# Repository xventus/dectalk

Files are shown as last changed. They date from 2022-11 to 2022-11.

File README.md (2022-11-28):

# DECTALK 

DECTALK is a simple application of Epson's S1V30120 chip. The communication is controlled by the ESP32 module. Esp32 provides HTTP and serial access for control. MIKROE produces a suitable module carrying the S1V30120 and an amplifier. 

The hardware directory contains a schematic and a board of plenum connections in KICAD format.
The src directory contains the source code for ESP32.

# How to use it 

The module can communicate using HTTP protocol via WiFi or using a serial link.

WiFi connection:
	- on first run, create an AP named `DECTALK CONFIG` or press reset (EN) twice within 5 seconds. 
	- web browser http://192.168.4.100 and fill in the web form

 	POST via build in fomular:  http://192.168.2.220/talk
 	POST via build in fomular:  http://192.168.2.220
	GET with url encoded string as param:   http://XXX.XXX.XXX.XXX/talk?talk=hello%20world

Serial line connection:
	- 9600.8.N.1 

LED status on the ESP32 module:
 - fast LED blinking - error, more detail after serial line
 - slow blinking LED - runs as AP `DECTALK CONFIG`
 - turns on and then off - when playing a message

# Device limitations

The message length is limited to 248 characters.

# Documentation 

S1V30120 module:  https://www.mikroe.com/text-to-speech-click.

S1V30120 initialization data: https://global.epson.com/products_and_drivers/semicon/products/speech/voice/sla/s1v30120_init_data.html

S1V30120 protocol: https://global.epson.com/products_and_drivers/semicon/pdf/id001875.pdf

# Screens

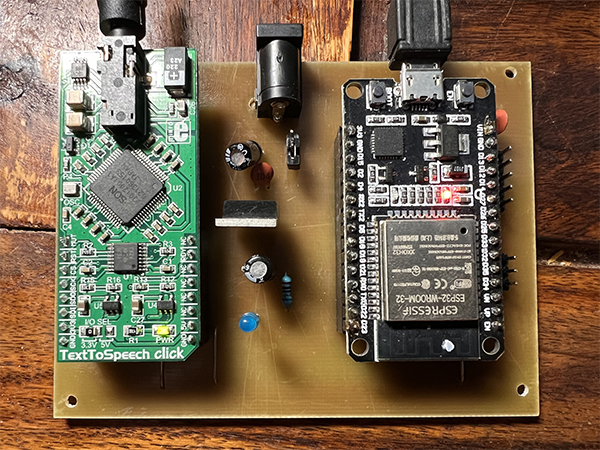
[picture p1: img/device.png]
device

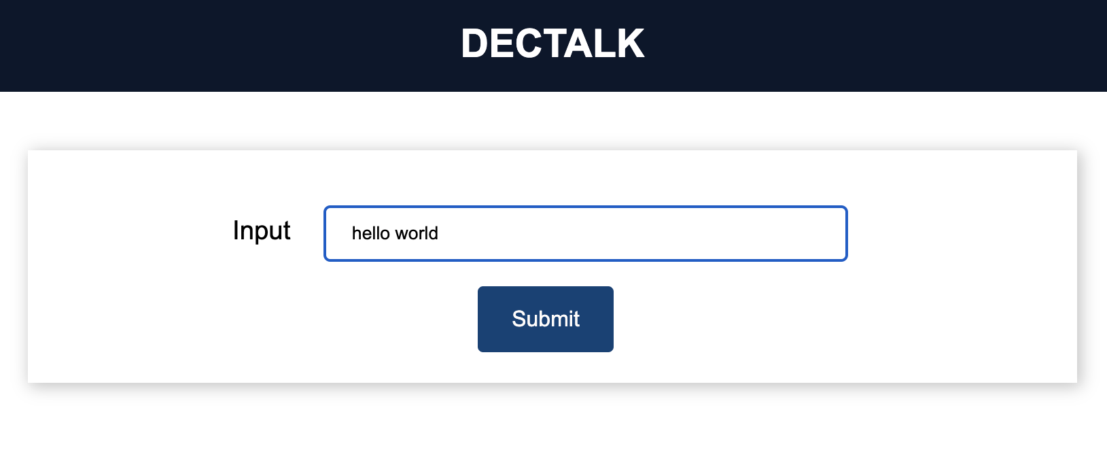
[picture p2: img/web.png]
dectalk screen

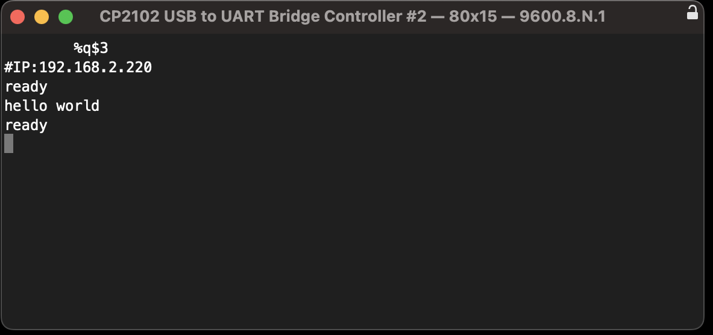
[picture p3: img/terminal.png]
terminal


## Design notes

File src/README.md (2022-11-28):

# Compilation for ESP32 module

1, Visual Studio Code + Platformio

2, in platformio.ini set the correct serial port e.g. upload_port = /dev/cu.usbserial-0001

3, upload to ESP32 filesytem using GUI - Upload Filesystem Image

4, upload own program - Upload

6, on first run, create an AP named `DECTALK CONFIG` or press reset (EN) twice within 5 seconds. 

7, web browser http://192.168.4.100 and fill in the web form

8, restart

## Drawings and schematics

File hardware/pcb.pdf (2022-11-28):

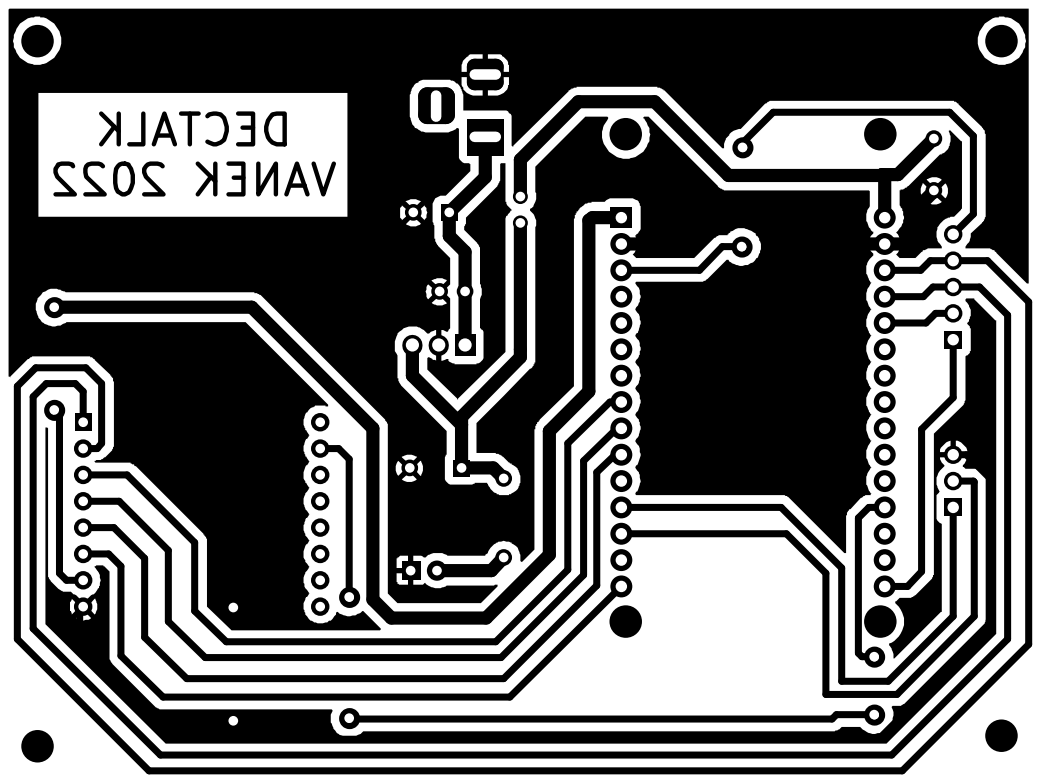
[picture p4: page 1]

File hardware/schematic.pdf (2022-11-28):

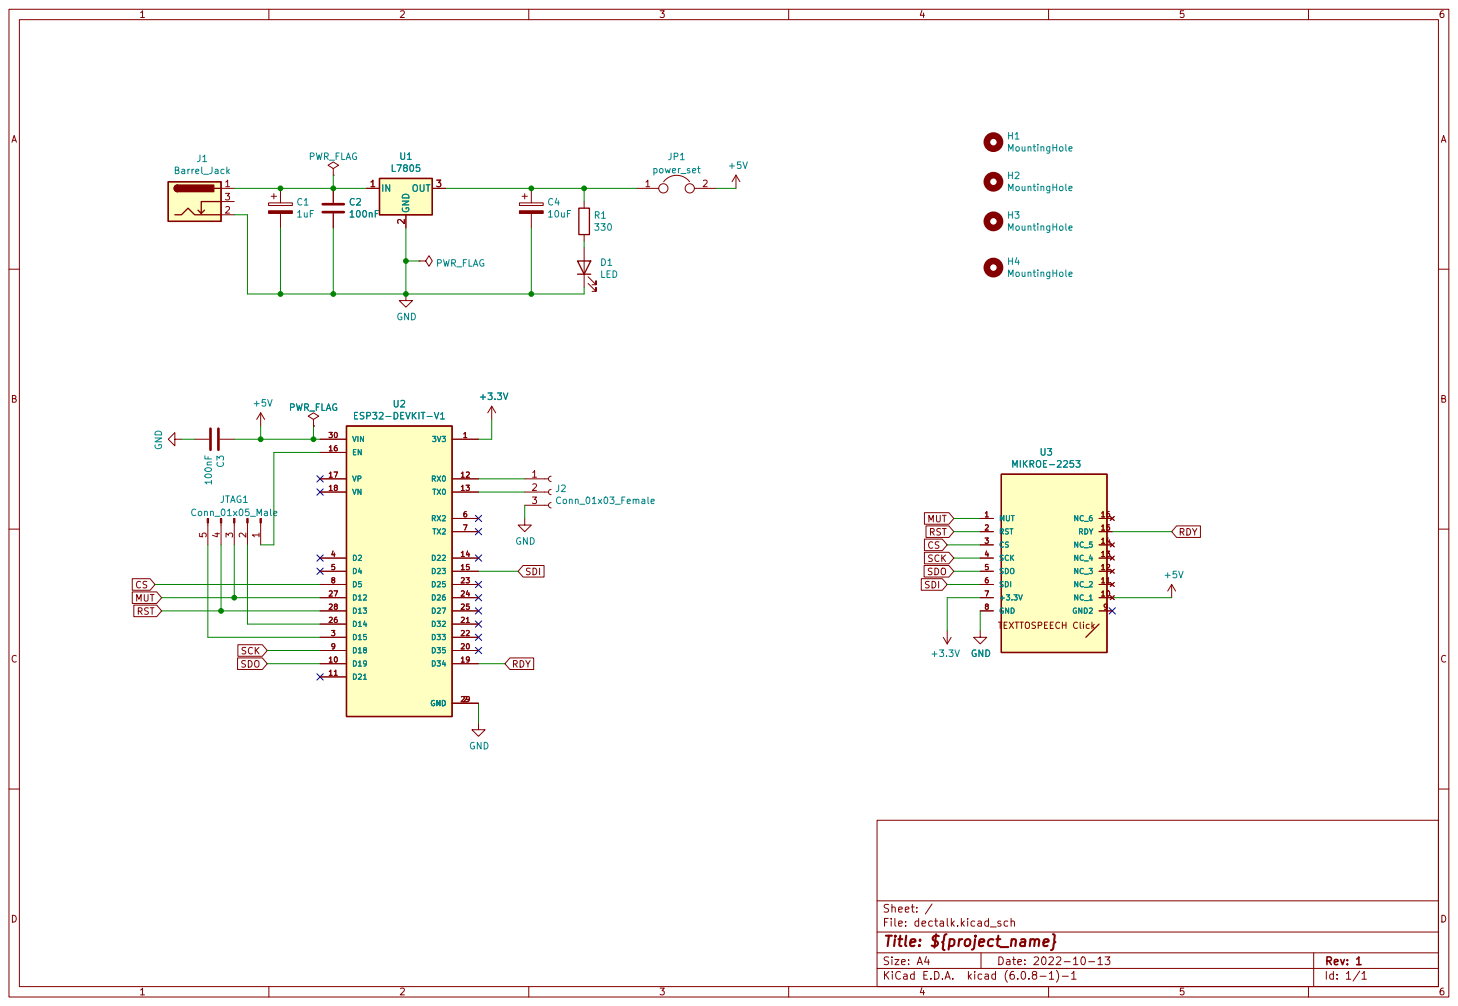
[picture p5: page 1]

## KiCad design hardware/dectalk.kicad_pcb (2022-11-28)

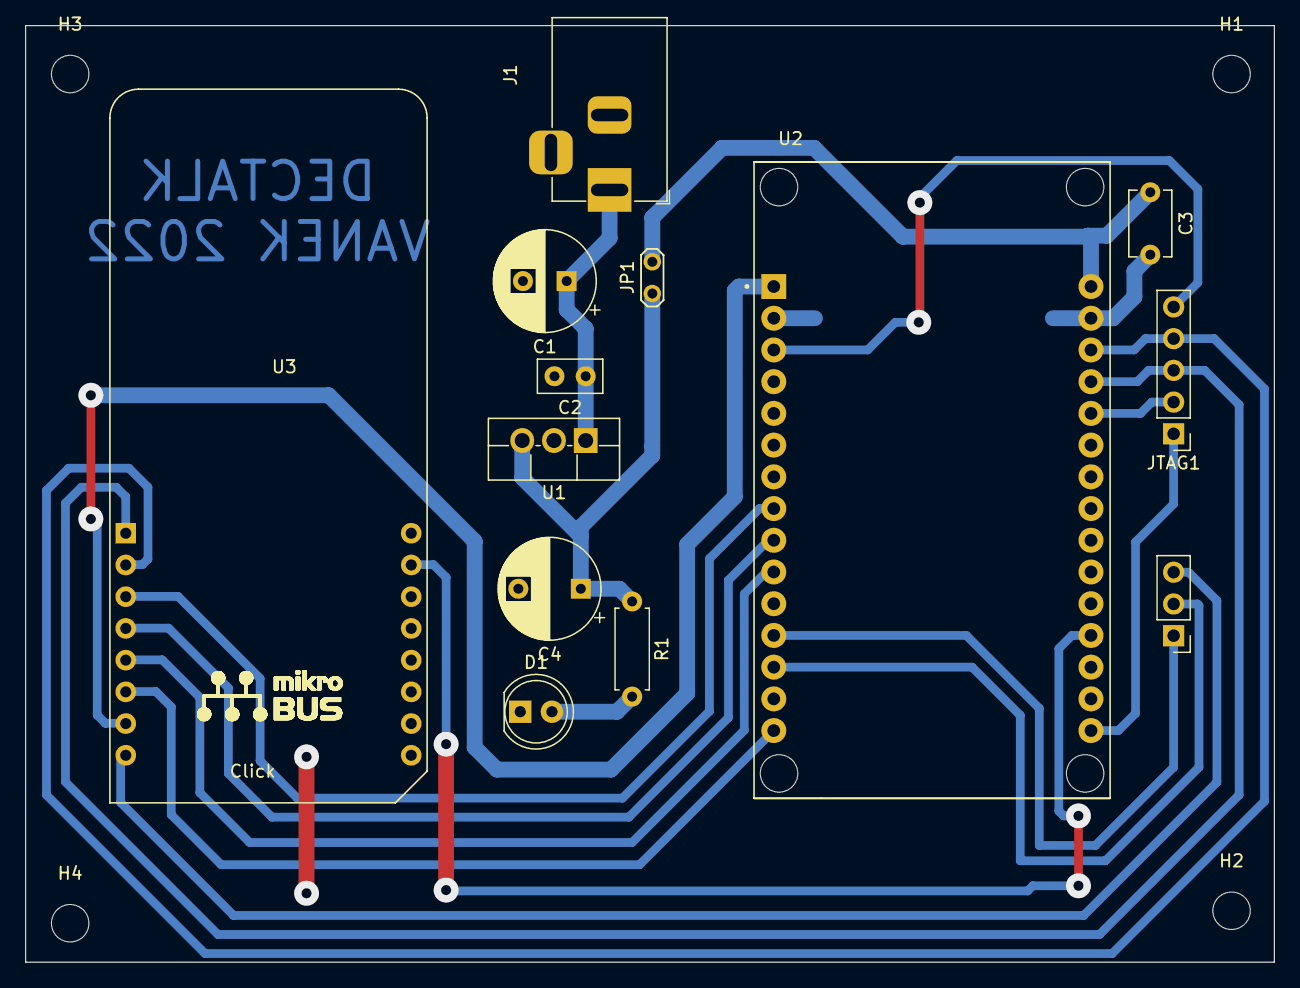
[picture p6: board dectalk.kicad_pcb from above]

Board: 2 copper layers, 100.0 x 75.0 mm, 17 parts (0 on the bottom side), 18 nets.

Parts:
C1: 1uF; CP_Radial_D8.0mm_P3.50mm
C2: 100nF; C_Disc_D5.0mm_W2.5mm_P2.50mm
C3: 100nF; C_Disc_D5.1mm_W3.2mm_P5.00mm
C4: 10uF; CP_Radial_D8.0mm_P5.00mm
D1: LED; LED_D5.0mm_IRGrey
H1, H2, H3, H4: MountingHole; MountingHole_3mm
J1: Barrel_Jack; BarrelJack_Horizontal
J2: Conn_01x03_Female; PinHeader_1x03_P2.54mm_Vertical
JP1: power_set; TestPoint_2Pads_Pitch2.54mm_Drill0.8mm
JTAG1: Conn_01x05_Male; PinHeader_1x05_P2.54mm_Vertical
R1: 330; R_Axial_DIN0207_L6.3mm_D2.5mm_P7.62mm_Horizontal
U1: L7805; TO-220F-3_Vertical
U2: ESP32-DEVKIT-V1; MODULE_ESP32_DEVKIT_V1
U3: MIKROE-2253

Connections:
+3V3: U2.1 (3V3), U3.7 (+3.3V)
+5V: C3.1, JP1.2, U2.30 (VIN)
CS: U2.8 (D5), U3.3 (CS)
GND: C1.2, C2.2, C3.2, C4.2, D1.1 (K), J1.2, J2.3, U1.2 (GND), U2.2 (GND), U2.29 (GND), U3.8 (GND)
MUT: JTAG1.3, U2.27 (D12), U3.1 (MUT)
unnamed: C1.1, C2.1, J1.1, U1.1 (IN)
unnamed: C4.1, JP1.1, R1.1, U1.3 (OUT)
unnamed: D1.2 (A), R1.2
unnamed: J2.1, U2.12 (RX0)
unnamed: J2.2, U2.13 (TX0)
unnamed: JTAG1.5, U2.3 (D15)
unnamed: JTAG1.1, U2.16 (EN)
unnamed: JTAG1.2, U2.26 (D14)
RDY: U2.19 (D34), U3.15 (RDY)
RST: JTAG1.4, U2.28 (D13), U3.2 (RST)
SCK: U2.9 (D18), U3.4 (SCK)
SDI: U2.15 (D23), U3.6 (SDI)
SDO: U2.10 (D19), U3.5 (SDO)

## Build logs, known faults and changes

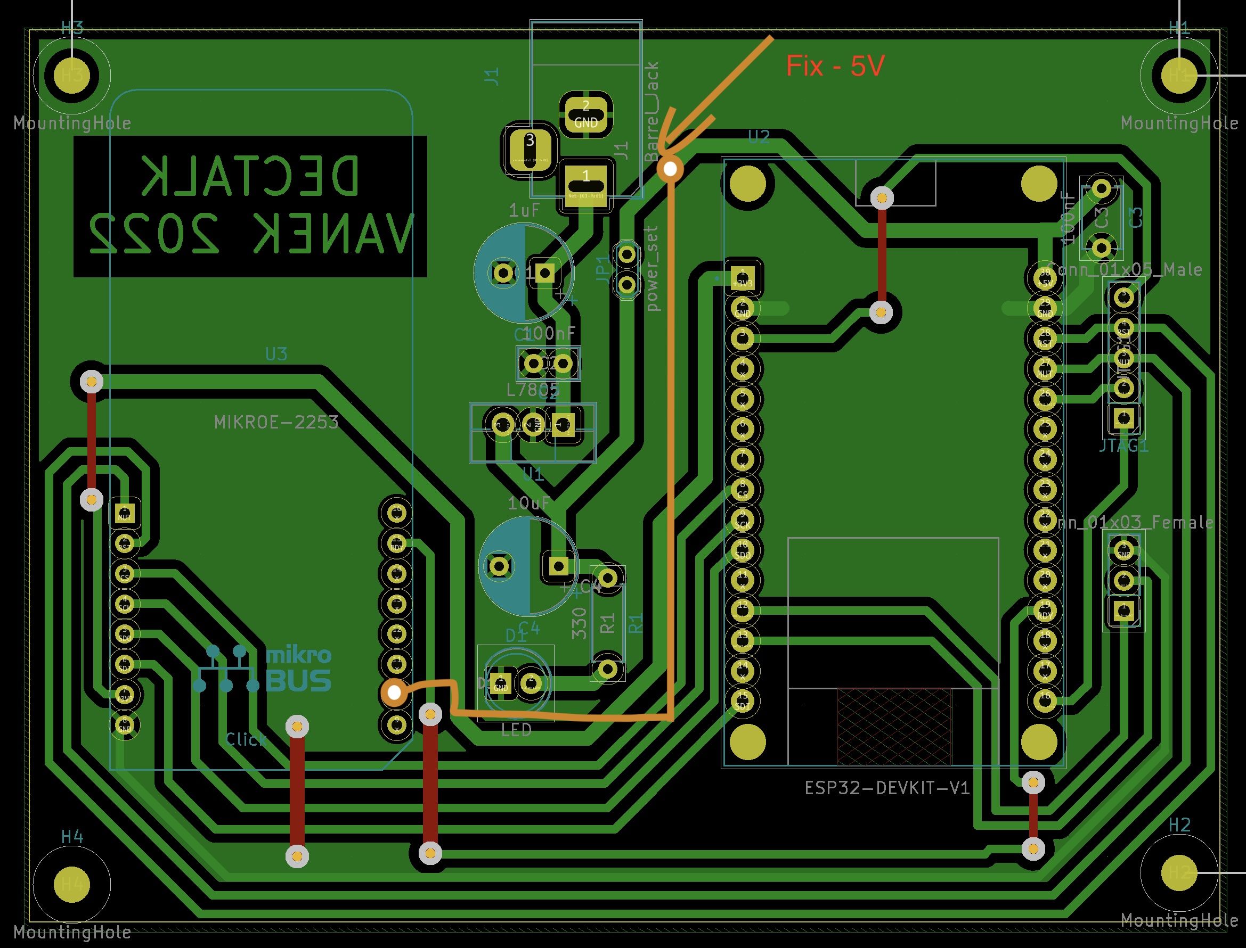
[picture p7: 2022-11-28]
hardware/PCB-WIRE-FIX.jpg

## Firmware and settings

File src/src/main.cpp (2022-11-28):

/**
 * @file main.cpp
 * @author Petr Vanek (petr@fotoventus.cz)
 * @brief Test application for S1V30120
 * @version 0.1
 * @date 2022-11-27
 *
 * @copyright Copyright (c) 2022 Petr Vanek
 *
 */
#include <Arduino.h>
#include <HardwareSerial.h>
#include <string.h>
#include "S1V30120.h"
#include "cfg_server.h"
#include "ap.h"
#include "configuration.h"
#include "dbl_reset.h"
#include "build_in_led.h"
#include <WiFi.h>
#include "talk_server.h"

// ESP32 - SPI - default pins
#define VSPI_MISO MISO
#define VSPI_MOSI MOSI
#define VSPI_SCLK SCK
#define VSPI_SS SS

// control pins for S1V30120
#define S1V30120_RST  13
#define S1V30120_RDY  34
#define S1V30120_MUTE 12

// TXT
const char *readyTxt = "[:name 3]  system ready"; 
const char *readylbl = "ready"; 
const char *waitlbl = "wait";
const char *errorlbl = "#error S1V30120"; 
const char *limitlbl = "limit error"; 



// globals
SPIClass *vspi = nullptr;
S1V30120 *talker = nullptr;
TalkServer *talsrv = nullptr;
String msg;
ItemFS ifs;
Configuration cfg;
DblReset dbl(&ifs);
BuildInLed  binled(2);


bool loadConfig() {
  bool rc = true;
  cfg.ssid = ifs.readItem(ItemFS::Data::ssid);
  cfg.pass = ifs.readItem(ItemFS::Data::password);
  cfg.ip = ifs.readItem(ItemFS::Data::ip);

  if (cfg.ssid.isEmpty() || cfg.pass.isEmpty()) rc = false;
  return rc;
}


/// @brief Creates an AccessPoint with a web server for configuration. 
void webConfig() {
  
    AP ap;
    CfgServer ws(&ifs);

    if (ap.init()) {
       binled.setState(BuildInLed::State::blink);
       Serial.printf("#Configuration IP: %s\n", ap.getIP().toString().c_str());
       Serial.printf("AP: %s,%s\n", ap.getIP().toString().c_str(), ap.getSSID());
       ws.init(80);
       ws.serveCfgPage();
       while(true)  { 
          binled.update();
          delay(200);
       }

    }
    Serial.printf("#Invalid AP INIT\nSTOP\n");
    binled.setState(BuildInLed::State::error);
    while(true) { binled.update(); }
}

/// @brief terminal input & web input
void setup()
{
  
  // sets serial to slow, compatible with retro computers 
  Serial.begin(9600);
  delay(100);
  Serial.println();
  
  binled.setState(BuildInLed::State::off);

  if (!ifs.init() || !ifs.isRequiredFileExists()) {
     Serial.printf("#Invalid file system, please 'Upload Filesystem Image'! \nSTOP\n");
     binled.setState(BuildInLed::State::error);
    while(true) { binled.update(); }
  }
  
  if (!loadConfig()) {
    Serial.printf("#configuration not found, use web config\n"); 
    webConfig();
  } 

  // configuration - double reset 
  if (dbl.isDblRestActivated()) {
        Serial.println("#double Reset");
        dbl.stop();
        Serial.printf("#filesystem content:\n"); 
        ifs.dumpFiles();
        webConfig();
  } 

  vspi = new SPIClass(VSPI);
  vspi->begin(VSPI_SCLK, VSPI_MISO, VSPI_MOSI, VSPI_SS);
  talker = new S1V30120(vspi, S1V30120_RST, S1V30120_RDY, S1V30120_MUTE);
  
  // decltalk mode
  if (!talker->init(false))
  {
      Serial.println(errorlbl);
      binled.setState(BuildInLed::State::error);
      while(true) { binled.update(); }
  }

  // connect to wifi
  binled.setState(BuildInLed::State::connecting);
  WiFi.begin(cfg.ssid.c_str(), cfg.pass.c_str());
  while (WiFi.status() != WL_CONNECTED) {
    delay(100);
  }

  Serial.print("#IP:");
  Serial.println(WiFi.localIP());
 
  binled.setState(BuildInLed::State::off);
  binled.update();

  /*
  // detail HW info
  Serial.print("#HW:");
  Serial.println(talker->getHWVersion(), HEX);
  Serial.print("#FW:");
  Serial.println(talker->getFWVersion(), HEX);
  Serial.print("#FEAT:");
  Serial.println(talker->getFWFeatures(), HEX);
  */

  binled.setState(BuildInLed::State::on);
  talker->speak(readyTxt, false, true);
  while (!talker->isFinished()) { binled.update(); }
  binled.setState(BuildInLed::State::off);
  binled.update();

  Serial.println(readylbl);
  msg.clear();

  talsrv = new TalkServer(&ifs, talker, &binled);
  talsrv->init(80);
  talsrv->serveTalkPage();

}

void flushInbound() {
  while(Serial.available() > 0) {
      Serial.read();
    }
}

void serialupdate() {
  // serial  
    while (Serial.available() > 0)
    {
      char ch = Serial.read();
     
      // echo
      Serial.print(ch);
      if (ch == 8 && msg.length() > 0) {
         // backspace
         msg.remove(msg.length()-1);
         continue;
      }

      if (ch == '\r')
      {
        Serial.print(msg.c_str());
        talker->speak(msg, false);
        binled.setState(BuildInLed::State::on);
        while (!talker->isFinished())  { binled.update(); }
        binled.setState(BuildInLed::State::off);
        binled.update();

        msg.clear();
        Serial.println();
        Serial.println(readylbl);
        flushInbound();
      }

      // ignore LF
      if (ch == '\n')
        continue;
      
      // maximum message size overflowed 
      if (msg.length() >= talker->maximumMsgSize) {
        Serial.println(limitlbl);
        msg.clear();
        continue;
      }

      msg += ch;
    }
}

void httpUpdate() {

  if (talker->isRunning()) {
    Serial.println(waitlbl);
    while (!talker->isFinished())  { binled.update(); }
    binled.setState(BuildInLed::State::off);
    binled.update();
    Serial.println(readylbl);
  }
  
}

void loop()
{
  serialupdate();
  httpUpdate();
  dbl.update();
}

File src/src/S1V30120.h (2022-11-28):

/**
 * @file S1V30120.h
 * @author Petr Vanek (petr@fotoventus.cz)
 * @brief Class for voice synthesizer control
 * @version 0.1
 * @date 2022-08-29
 *
 * @copyright Copyright (c) 2022 Petr Vanek (petr@fotoventus.cz)
 *
 *
 */
#pragma once

#include <inttypes.h>
#include <string.h>
#include "S1V30120_const.h"
#include "S1V30120_init_data.h"
#include <SPI.h>
#include <mutex>

class S1V30120
{

public:

    static const uint16_t maximumMsgSize = 248;//121;
    static const uint16_t maximumBufferSize = maximumMsgSize + 7;

    /**
     * @brief Construct a new S1V30120 object
     *
     * @param spi   - SPI object
     * @param resetPin  - reset pin - NRESET
     * @param rdyPin    - ready pin - GPIOA3
     * @param mutePin   - mute aplifier, e.g. LM386 - gain
     */
    explicit S1V30120(SPIClass* spi, uint8_t resetPin, uint8_t rdyPin, uint8_t mutePin) : _spi(spi),
                                                                                         _resetPin(resetPin),
                                                                                         _rdyPin(rdyPin),
                                                                                         _mutePin(mutePin)
    {
        pinMode(_spi->pinSS(), OUTPUT); // CS
        pinMode(_resetPin, OUTPUT);     // RESET
        pinMode(_rdyPin, INPUT);        // RDY
        pinMode(_mutePin, OUTPUT);      // MUTE
    }

    
    /**
     * @brief S1V30120 initialization and firmware upload. Repeated calls are possible.
     * 
     * @param epson  - true - Epson parse, false DECtalk
     * @return true if success 
     * @return false 
     */
    bool init(bool epson = false)
    {
        auto rc = false;
        std::lock_guard<std::mutex> lck(_mtx);
        do
        {
            reset(); 

            // verify IC availability and find out the HW version
            if (!version()) 
                break;

            // upload firmware
            if (!uploadFW())
                break;

            // run firmware
            if (!run()) 
                break;   

            // registration 
            if (!test()) 
                break;   

            // check FW version
            if (!version()) 
                break;  

            // audio configuration
            if (!audioCfg()) 
                break; 

            // maximum volume
            if (! maxVolume()) 
                break; 
 
            // TTS
            if (! setupTTS(epson)) 
                break; 

            rc = true;
        } while (false);
        return rc;
    }

// 0x00 – flush disabled – this string is spoken after any previous speak requests have been finished. 
// 0x01 – flush enabled – this TTS output is flushed and the current string is spoken immediately
    
    /**
     * @brief 
     * 
     * @param text  - the text of the message
     * @param flush -  true =  this TTS output is flushed and the current string is spoken immediately
     *                 false= this string is spoken after any previous speak requests have been finished
     * @return true 
     * @return false 
     */

    /// @brief plays a text message with a maximum length of maximumMsgSize characters
    /// @param text the text of the message
    /// @param mute  true - muted
    /// @param flush true =  this TTS output is flushed and the current string is spoken immediately
    ///              false= this string is spoken after any previous speak requests have been finished
    /// @return true / false
    bool speak(const String &text, bool mute = false, bool flush = true)
    {
        std::lock_guard<std::mutex> lck(_mtx);
        
        if (text.isEmpty()) return true;

        _inaction = true;
        
        digitalWrite(_mutePin, mute);
        
        memset(_buffer,0,sizeof(_buffer));
        auto sz = text.length();
        if (sz > maximumMsgSize) sz = maximumMsgSize;
        auto len = sz + 6;
        _buffer[0] = len & 0xFF;          
        _buffer[1] = (len & 0xFF00) >> 8; 
        _buffer[2] = ISC_TTS_SPEAK_REQ & 0xFF;
        _buffer[3] = (ISC_TTS_SPEAK_REQ & 0xFF00) >> 8;
        _buffer[4] = flush ? 0x01 : 0x00; 

        for (auto i = 0; i < sz; i++)
        {
            _buffer[i+5] = text[i];
        }

        sendMsg((uint8_t*) _buffer, len);
        return checkResponse(ISC_TTS_SPEAK_RESP, 0x0000, 16);
    }

    /// @brief is already speak finished
    /// @return 
    bool isFinished() {
        std::lock_guard<std::mutex> lck(_mtx);
        _inaction = !checkResponse(ISC_TTS_FINISHED_IND, 0x0000, 16); 
        return !_inaction; 
    }

    bool isRunning() {
        std::lock_guard<std::mutex> lck(_mtx);
        return _inaction;
    }

    /// @brief hardware version
    /// @return version or zero if failed
    uint16_t getHWVersion() const
    {
        return _versionHW;
    }

    /// @brief firmware version
    /// @return version or zero if failed
    uint16_t getFWVersion() const
    {
        return _versionFW;
    }

    uint32_t getFWFeatures() const
    {
        return _versionFWFeatures;
    }
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
